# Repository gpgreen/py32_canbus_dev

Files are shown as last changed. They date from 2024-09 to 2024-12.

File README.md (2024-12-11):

# py32_canbus_dev

KiCad design for a ARM Cortex-M0+ CAN bus development board with a
MCP2518 CAN FD controller. The mcu part is a Puya PY032F030K18T6. This
can run at a maximum of 48 MHz, and has 8 kbyte SRAM and 64 kbyte
Flash. A USB B mini connector provides 5V power and interfaces with a
FTDI device wired as a Serial Comm to the development board. There is
an onboard LDO that provides 500mA of power at 3.3V. An LED is
connected to 1 of the GPIO pins. All available GPIO pins are routed to
the 2 18pin headers.

The board must be programmed with a debugger, ie at this time it
cannot be programmed over the usb.

## Changes

- Rev A
  Original

## Firmware

Example firmware that blinks the LED. This firmware
uses the HAL provided by Puya and is in C.

https://github.com/gpgreen/py32-dev-blink

## Boot configuration

A boot configuration must be selected for the development board to
operate. If a program has been flashed then booting from main flash
should be selected for that program to run.

To boot from main flash [0x0800_0000] Connect J2-4 to J2-5 (or) solder
  JP5-1 to center post

To boot from System mem [0x1FFF_0000], or Embedded SRAM [0x2000_0000]
  Connect J2-4 to J2-3 (or) solder JP6-3 to center post

There is an embedded boot loader, programmed during mcu chip
production, in the system memory block. See the reference manual
3.6.2.

## PIN JUMPER SIGNAL ASSIGNMENT
```
                     USB-B
                    +-----+
            +--------------------+
            |J3     |     |    J2|
        VDD-|1      +-----+     1|-GND
        GND-|2                  2|-GND
       +3.3-|3                  3|-+3.3
[RESET] PF2-|4                  4|-PF4 [BOOT0_PRE]
[SWCLK]PA14-|5                  5|-GND
[SWDIO]PA13-|6                  6|-GND
        GND-|7       RST        7|-GND
        PF3-|8       +-+        8|-PB7 [USB RX]
        PA0-|9       |O|        9|-PB6 [USB TX]
  [SCK] PA1-|10      +-+       10|-PB5
 [MOSI] PA2-|11                11|-PB4
        PA3-|12                12|-PB3
  [NSS] PA4-|13                13|-PA15
[CAN I] PA5-|14                14|-PA12 [USER LED - GREEN]
 [MISO] PA6-|15                15|-PA11
        PA7-|16                16|-PA10
        PB0-|17                17|-PA9
        PB1-|18    +------+    18|-PA8
            |     1| o  o |2     |
            +--------------------+
                     H  L
                     CAN
```
## Links
- [Puya PY32 Series](https://www.puyasemi.com/cpzx3/info_271_aid_247_kid_246.html)
- [Software template for PY32 Series by Jay Carlson](https://github.com/jaydcarlson/py32-template)
- [Fork of template for these boards](https://github.com/gpgreen/py32-dev-blink)
- [Firmware library for py32f030](https://www.puyasemi.com/download_path/%E5%BA%93%E5%87%BD%E6%95%B0%E4%B8%8E%E4%BE%8B%E7%A8%8B/MCU/PY32F0xx_Firmware_V1.4.1.zip)

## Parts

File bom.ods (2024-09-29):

Reference | Value | Datasheet | Footprint | Qty | DNP | LCSC #
C1 | 10nF | ~ | Capacitor_Tantalum_SMD:CP_EIA-3216-18_Kemet-A_Pad1.58x1.35mm_HandSolder | 1
C2 | 0.33uf | ~ | Capacitor_Tantalum_SMD:CP_EIA-3216-18_Kemet-A_Pad1.58x1.35mm_HandSolder | 1
C3 | 10uf | ~ | Capacitor_Tantalum_SMD:CP_EIA-3216-18_Kemet-A_Pad1.58x1.35mm_HandSolder | 1
C4,C5,C11,C12,C14 | 0.1uf | ~ | Capacitor_SMD:C_0603_1608Metric | 5
C6,C7,C8,C9 | 22pf | ~ | Capacitor_SMD:C_0603_1608Metric | 4
C10,C13,C15 | 0.1 uF | ~ | Capacitor_SMD:C_0603_1608Metric | 3
D1 | RED | ~ | Diode_SMD:D_0603_1608Metric | 1
D2 | GREEN | ~ | Diode_SMD:D_0603_1608Metric | 1
D3 | CDSOT23-T24CAN | https://www.littelfuse.com/~/media/electronics/datasheets/tvs_diode_arrays/littelfuse_tvs_diode_array_sm712_datasheet.pdf.pdf | Package_TO_SOT_SMD:SOT-23 | 1 |  | C350941
FB1 | CBG321609U121T | ~ | Inductor_SMD:L_1206_3216Metric | 1 |  | C39279
H1,H2,H3,H4 | MountingHole | ~ | MountingHole:MountingHole_2.5mm_Pad | 4
J2,J3 | Conn_01x18 | ~ | Connector_PinHeader_2.54mm:PinHeader_1x18_P2.54mm_Vertical | 2
J4 | CAN1 | ~ | Connector_JST:JST_EH_B2B-EH-A_1x02_P2.50mm_Vertical | 1
J5 | USB_B_Micro | SOFNG MC-101G | Connector_USB:USB_Micro-B_Amphenol_10103594-0001LF_Horizontal | 1 |  | C498180
JP5 | Boot | ~ | Jumper:SolderJumper-3_P1.3mm_Open_Pad1.0x1.5mm_NumberLabels | 1
R1 | 470 | ~ | Resistor_SMD:R_0603_1608Metric | 1
R4 | 120 | ~ | Resistor_SMD:R_1206_3216Metric | 1
R5,R7 | 10K | ~ | Resistor_SMD:R_0603_1608Metric | 2
R6 | 680 | ~ | Resistor_SMD:R_0603_1608Metric | 1
SW2 | Reset | ~ | Button_Switch_SMD:SW_Push_1P1T_NO_Vertical_Wuerth_434133025816 | 1
U1 | UA78M33CDCYR | http://www.ti.com/lit/ds/symlink/ua78.pdf | Package_TO_SOT_SMD:SOT-223-3_TabPin2 | 1 |  | C49036
U2 | PY32F030K1xT |  | Package_QFP:LQFP-32_7x7mm_P0.8mm | 1
U3 | MCP2518FD-E/QBB | https://ww1.microchip.com/downloads/aemDocuments/documents/OTH/ProductDocuments/DataSheets/External-CAN-FD-Controller-with-SPI-Interface-DS20006027B.pdf | Package_DFN_QFN:DFN-14-1EP_3x4.5mm_P0.65mm_EP1.65x4.25mm | 1 |  | C621395
U4 | MCP2562FD-E/MF | http://ww1.microchip.com/downloads/en/DeviceDoc/25167A.pdf | Custom:MICROCHIP-DFN-3x3x0.9mm-8P | 1 |  | C635114
U5 | FT230XQ | https://www.ftdichip.com/Support/Documents/DataSheets/ICs/DS_FT230X.pdf | Package_DFN_QFN:QFN-16-1EP_4x4mm_P0.65mm_EP2.1x2.1mm | 1 |  | C128629
Y1 | 24MHz | ~ | Crystal:Crystal_SMD_TXC_7M-4Pin_3.2x2.5mm | 1
Y2 | 40MHz | ~ | Crystal:Crystal_SMD_TXC_7M-4Pin_3.2x2.5mm | 1

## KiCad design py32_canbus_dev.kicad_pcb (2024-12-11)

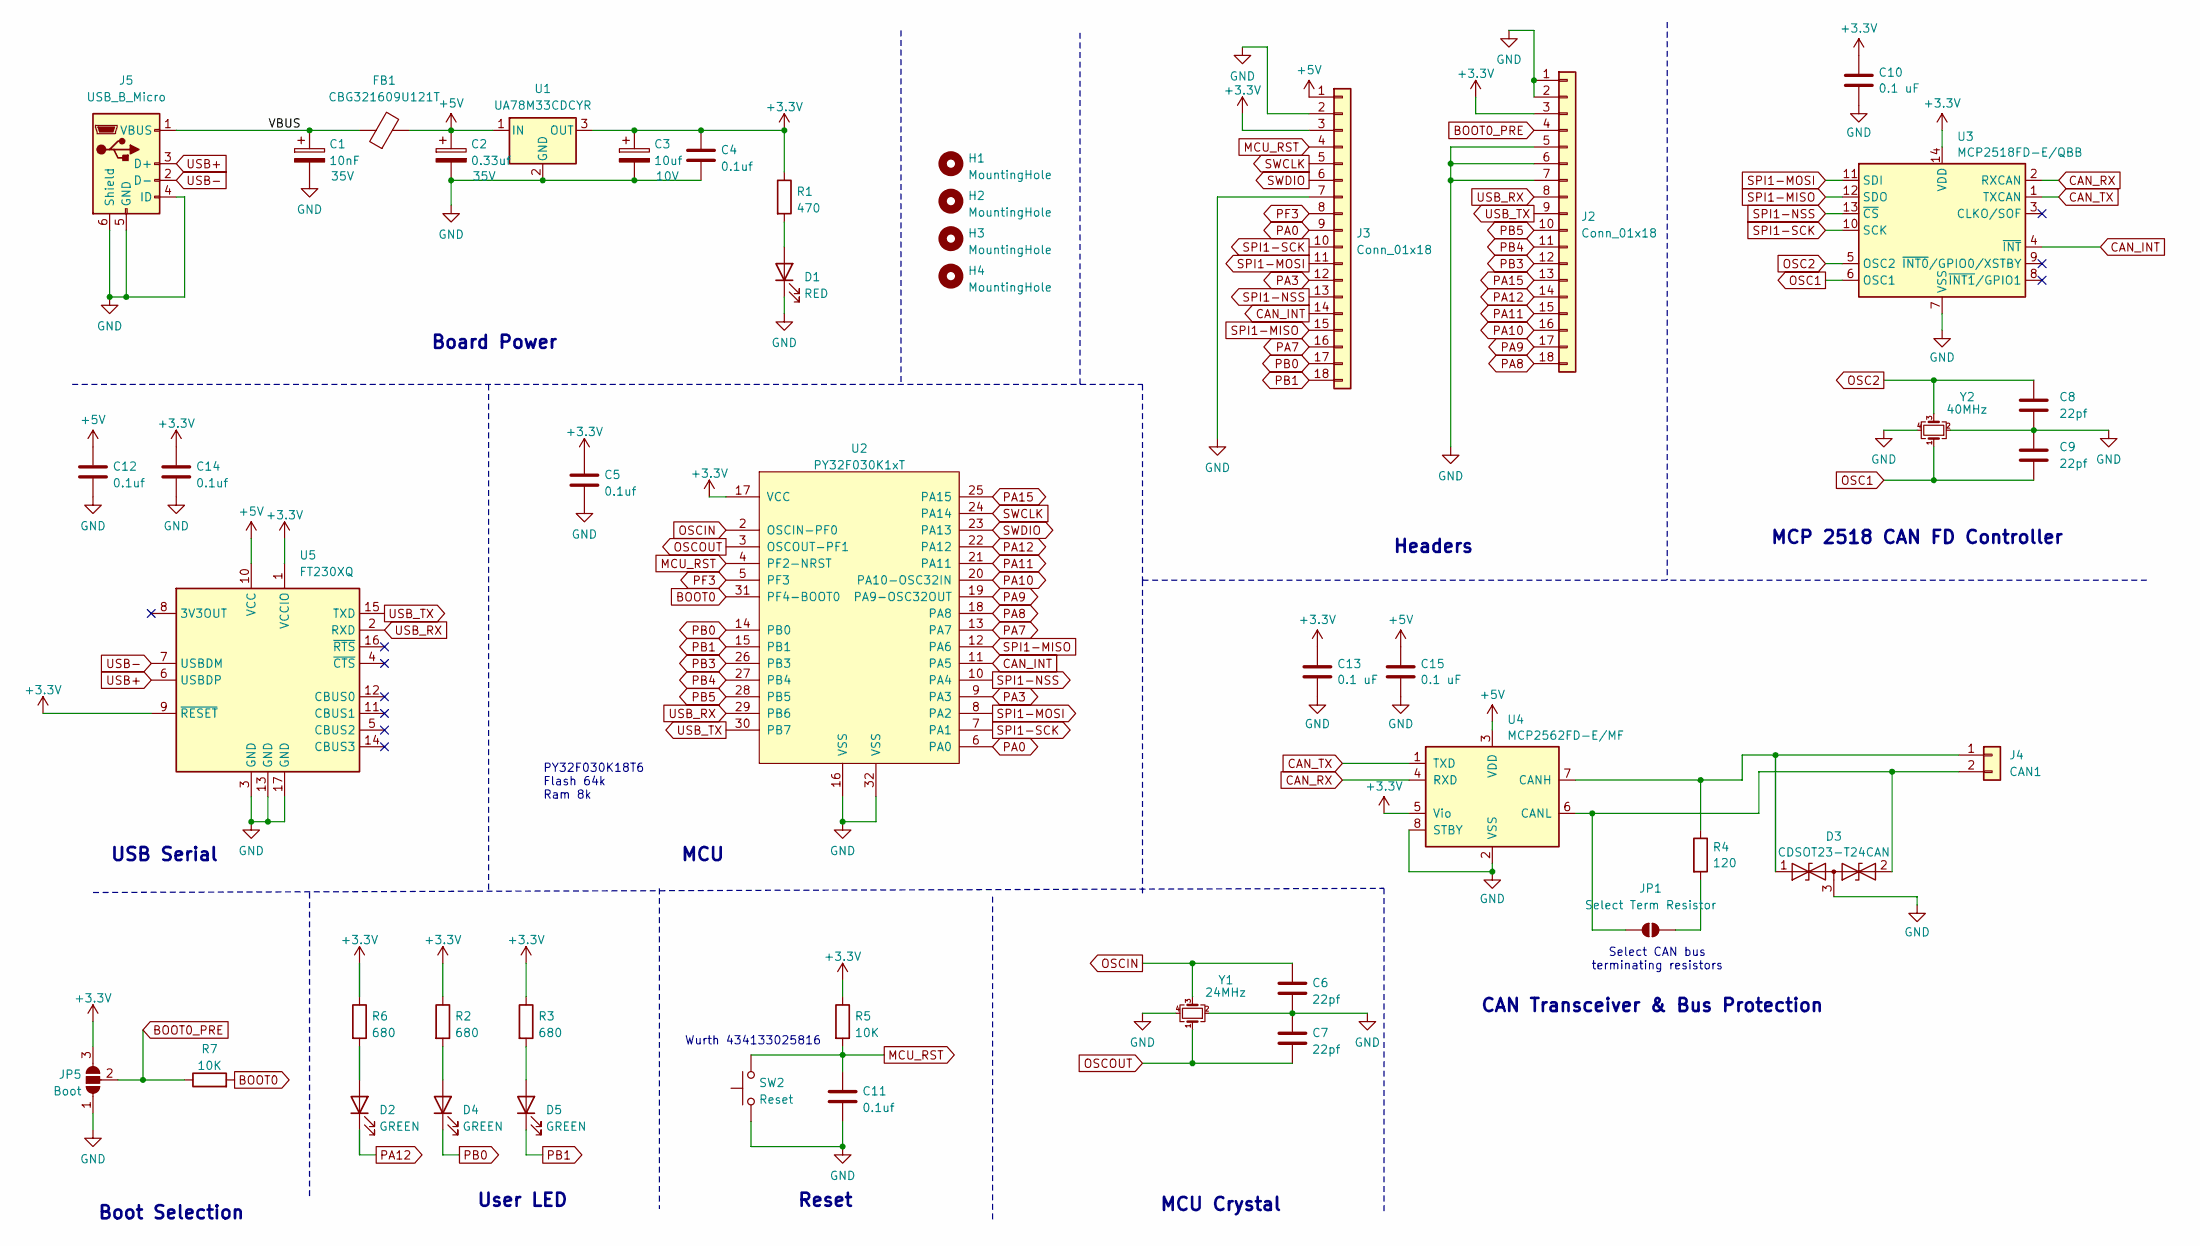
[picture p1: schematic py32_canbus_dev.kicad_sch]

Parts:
C1: 10nF; CP_EIA-3216-18_Kemet-A_Pad1.58x1.35mm_HandSolder; Voltage 35V
C2: 0.33uf; CP_EIA-3216-18_Kemet-A_Pad1.58x1.35mm_HandSolder; Voltage 35V
C3: 10uf; CP_EIA-3216-18_Kemet-A_Pad1.58x1.35mm_HandSolder; Voltage 10V
C4, C5, C11, C12, C14: 0.1uf; C_0603_1608Metric
C6, C7, C8, C9: 22pf; C_0603_1608Metric
C10, C13, C15: 0.1 uF; C_0603_1608Metric
D1: RED; D_0603_1608Metric
D2, D4, D5: GREEN; D_0603_1608Metric
D3: CDSOT23-T24CAN; SOT-23
FB1: CBG321609U121T; L_1206_3216Metric
H1, H2, H3, H4: MountingHole; MountingHole_3.2mm_M3
J2, J3: Conn_01x18; PinHeader_1x18_P2.54mm_Vertical
J4: CAN1; JST_EH_B2B-EH-A_1x02_P2.50mm_Vertical
J5: USB_B_Micro; USB_Micro-B_Amphenol_10103594-0001LF_Horizontal
JP1: Select Term Resistor; SolderJumper-2_P1.3mm_Open_Pad1.0x1.5mm
JP5: Boot; SolderJumper-3_P1.3mm_Open_Pad1.0x1.5mm_NumberLabels
R1: 470; R_0603_1608Metric
R2, R3, R6: 680; R_0603_1608Metric
R4: 120; R_1206_3216Metric
R5, R7: 10K; R_0603_1608Metric
SW2: Reset; SW_Push_1P1T_NO_Vertical_Wuerth_434133025816
U1: UA78M33CDCYR; SOT-223-3_TabPin2
U2: PY32F030K1xT; LQFP-32_7x7mm_P0.8mm
U3: MCP2518FD-E/QBB; DFN-14-1EP_3x4.5mm_P0.65mm_EP1.65x4.25mm
U4: MCP2562FD-E/MF; MICROCHIP-DFN-3x3x0.9mm-8P
U5: FT230XQ; QFN-16-1EP_4x4mm_P0.65mm_EP2.1x2.1mm
Y1: 24MHz; Crystal_SMD_TXC_7M-4Pin_3.2x2.5mm
Y2: 40MHz; Crystal_SMD_TXC_7M-4Pin_3.2x2.5mm

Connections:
+3.3V: C3.1, C4.1, C5.1, C10.1, C13.1, C14.1, J2.3, J3.3, JP5.3 (B), R1.1, R2.1, R3.1, R5.1, R6.1, U1.3 (OUT), U2.17 (VCC), U3.14 (VDD), U4.5 (Vio), U5.1 (VCCIO), U5.9 (~RESET)
+5V: C2.1, C12.1, C15.1, FB1.2, J3.1, U1.1 (IN), U4.3 (VDD), U5.10 (VCC)
/VBUS: C1.1, FB1.1, J5.1 (VBUS)
BOOT0: R7.2, U2.31 (PF4-BOOT0)
BOOT0_PRE: J2.4, JP5.2 (C), R7.1
CAN_INT: J3.14, U2.11 (PA5), U3.4 (~INT)
CAN_RX: U3.2 (RXCAN), U4.4 (RXD)
CAN_TX: U3.1 (TXCAN), U4.1 (TXD)
GND: C1.2, C2.2, C3.2, C4.2, C5.2, C6.2, C7.1, C8.2, C9.2, C10.2, C11.2, C12.2, C13.2, C14.2, C15.2, D1.1 (K), D3.3 (common), J2.1, J2.2, J2.5, J2.6, J2.7, J3.2, J3.7, J5.4 (ID), J5.5 (GND), J5.6 (Shield), JP5.1 (A), SW2.1, U1.2 (GND), U2.16 (VSS), U2.32 (VSS), U3.7 (VSS), U3.15 (VSS), U4.2 (VSS), U4.8 (STBY), U5.3 (GND), U5.13 (GND), U5.17 (GND), Y1.2, Y1.4, Y2.2, Y2.4
MCU_RST: C11.1, J3.4, R5.2, SW2.2, U2.4 (PF2-NRST)
unnamed: D1.2 (A), R1.2
unnamed: D2.2 (A), R6.2
unnamed: D3.1 (A1), J4.1, R4.1, U4.7 (CANH)
unnamed: D3.2 (A2), J4.2, JP1.1 (A), U4.6 (CANL)
unnamed: D4.2 (A), R2.2
unnamed: D5.2 (A), R3.2
unnamed: JP1.2 (B), R4.2
OSC1: C9.1, U3.6 (OSC1), Y2.1
OSC2: C8.1, U3.5 (OSC2), Y2.3
OSCIN: C6.1, U2.2 (OSCIN-PF0), Y1.3
OSCOUT: C7.2, U2.3 (OSCOUT-PF1), Y1.1
PA0: J3.9, U2.6 (PA0)
PA3: J3.12, U2.9 (PA3)
PA7: J3.16, U2.13 (PA7)
PA8: J2.18, U2.18 (PA8)
PA9: J2.17, U2.19 (PA9-OSC32OUT)
PA10: J2.16, U2.20 (PA10-OSC32IN)
PA11: J2.15, U2.21 (PA11)
PA12: D2.1 (K), J2.14, U2.22 (PA12)
PA15: J2.13, U2.25 (PA15)
PB0: D4.1 (K), J3.17, U2.14 (PB0)
PB1: D5.1 (K), J3.18, U2.15 (PB1)
PB3: J2.12, U2.26 (PB3)
PB4: J2.11, U2.27 (PB4)
PB5: J2.10, U2.28 (PB5)
PF3: J3.8, U2.5 (PF3)
SPI1-MISO: J3.15, U2.12 (PA6), U3.12 (SDO)
SPI1-MOSI: J3.11, U2.8 (PA2), U3.11 (SDI)
SPI1-NSS: J3.13, U2.10 (PA4), U3.13 (~CS)
SPI1-SCK: J3.10, U2.7 (PA1), U3.10 (SCK)
SWCLK: J3.5, U2.24 (PA14)
SWDIO: J3.6, U2.23 (PA13)
USB+: J5.3 (D+), U5.6 (USBDP)
USB-: J5.2 (D-), U5.7 (USBDM)
USB_RX: J2.8, U2.29 (PB6), U5.2 (RXD)
USB_TX: J2.9, U2.30 (PB7), U5.15 (TXD)

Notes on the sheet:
Select CAN bus terminating resistors
Headers
Boot Selection
MCU Crystal
Reset
MCP 2518 CAN FD Controller
MCU
USB Serial
Wurth 434133025816
CAN Transceiver & Bus Protection
PY32F030K18T6 Flash 64k Ram 8k
Board Power
User LED

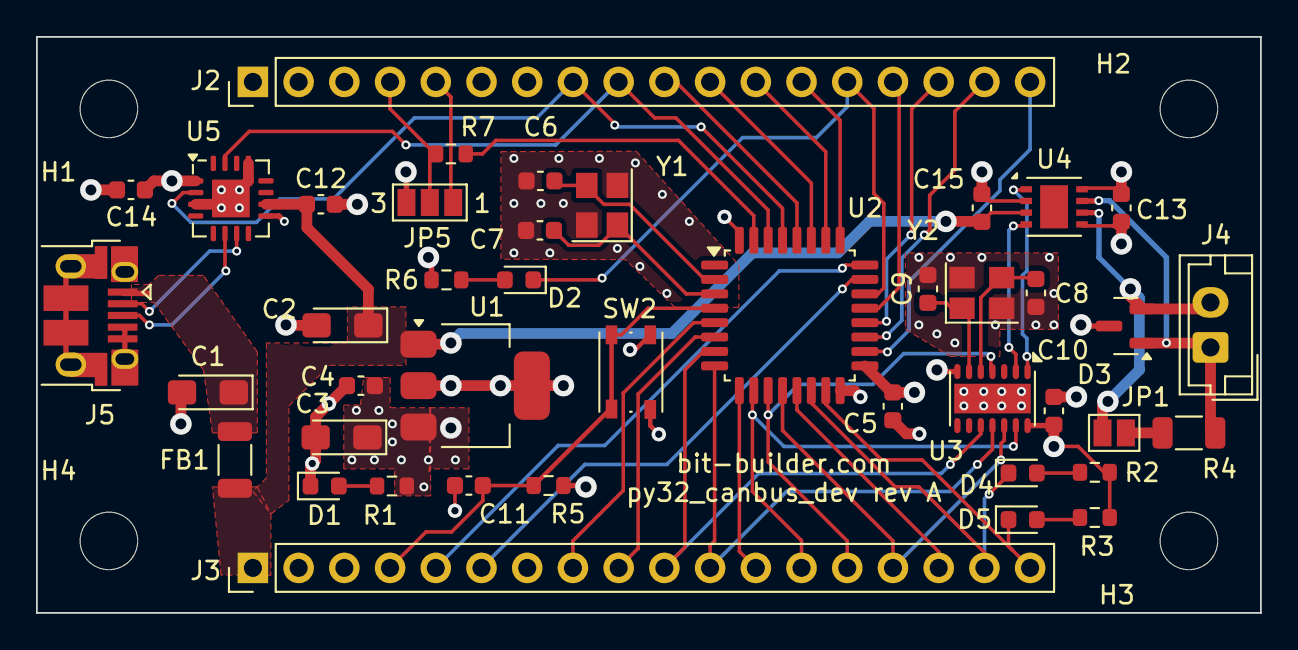
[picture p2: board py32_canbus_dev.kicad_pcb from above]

Board: 4 copper layers, 68.0 x 32.0 mm, 46 parts (0 on the bottom side), 46 nets.

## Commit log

2024-09-29 Completed schematic and pcb check
    [py32_canbus_dev.kicad_pcb, py32_canbus_dev.kicad_sch]
2024-09-29 Removed VDD
    Adding LCSC part numbers to BOM
    [bom.ods, py32_canbus_dev.kicad_pcb, py32_canbus_dev.kicad_sch]
2024-10-06 Showed new pin labels
2024-10-08 Fixed usb tx and rx
    [py32_canbus_dev.kicad_pcb, py32_canbus_dev.kicad_sch]
2024-12-11 Upped hole diameter, added 2 leds
    [py32_canbus_dev.kicad_pcb, py32_canbus_dev.kicad_sch]
